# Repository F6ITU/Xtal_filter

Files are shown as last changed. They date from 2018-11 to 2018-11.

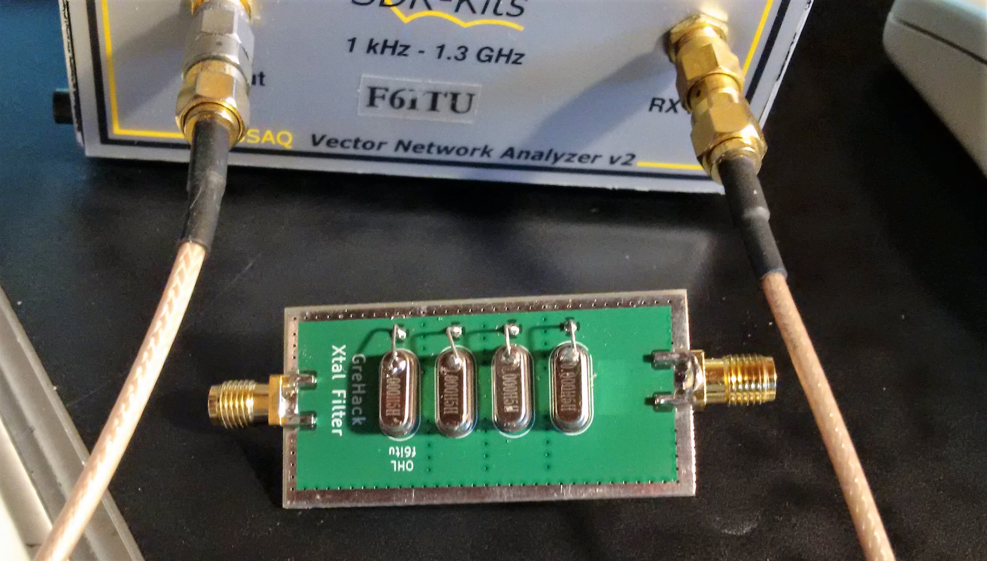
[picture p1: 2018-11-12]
Simu/filtre.jpg

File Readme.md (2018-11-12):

A simple 4th order 10 MHz xtal filter for Grehack 2018 Workshop

A Kicad project for GreHack 2018 workshop

This repository contains a easy to build-easy to reproduce 4th order filter using low cost 10 MHz crystal device in HC49 form factor.

This filter has been designed for educational purpose, and could be the perfect companion for a 10 MHz harmonic-free reference clock 
(gps-do, ocxo or any kind of digitaly generated square wave RF source)

This filter could be used in conjunction with the OCXO based "Aion" reference clock 

https://github.com/F6ITU/OCXO

This board has been designed with Kicad, an Open Source EDA software developped by the CERN.

For better performances, noise imunity and port isolation, this board should be shielded. 

The "Simu" subdirectory contains several simulation and measurement files : 
* 10M-4-5kHz 337ohms 47pf.sch is the "ADDE Filter design" simulation file and schematics of the filter itself
* BOM.doc is the Bill of Material used during the Grehack 2018 workshop
* filtre 10 MHz 4 eme ordre2.png is a screen capture of the filter's response measured with a Network Analyzer (Smith chart and amplitude/insertion losses) 
* filtre 10 MHz 4eme ordre.s2p is the real characteristic of the filter (2 port Touchstone file format). This file could be 
imported in any kind or analyzer or RF simulation software (QUCS, Elsie, VNWA.exe etc)
* filtre.jpg is a picture of the filter itself, without shield

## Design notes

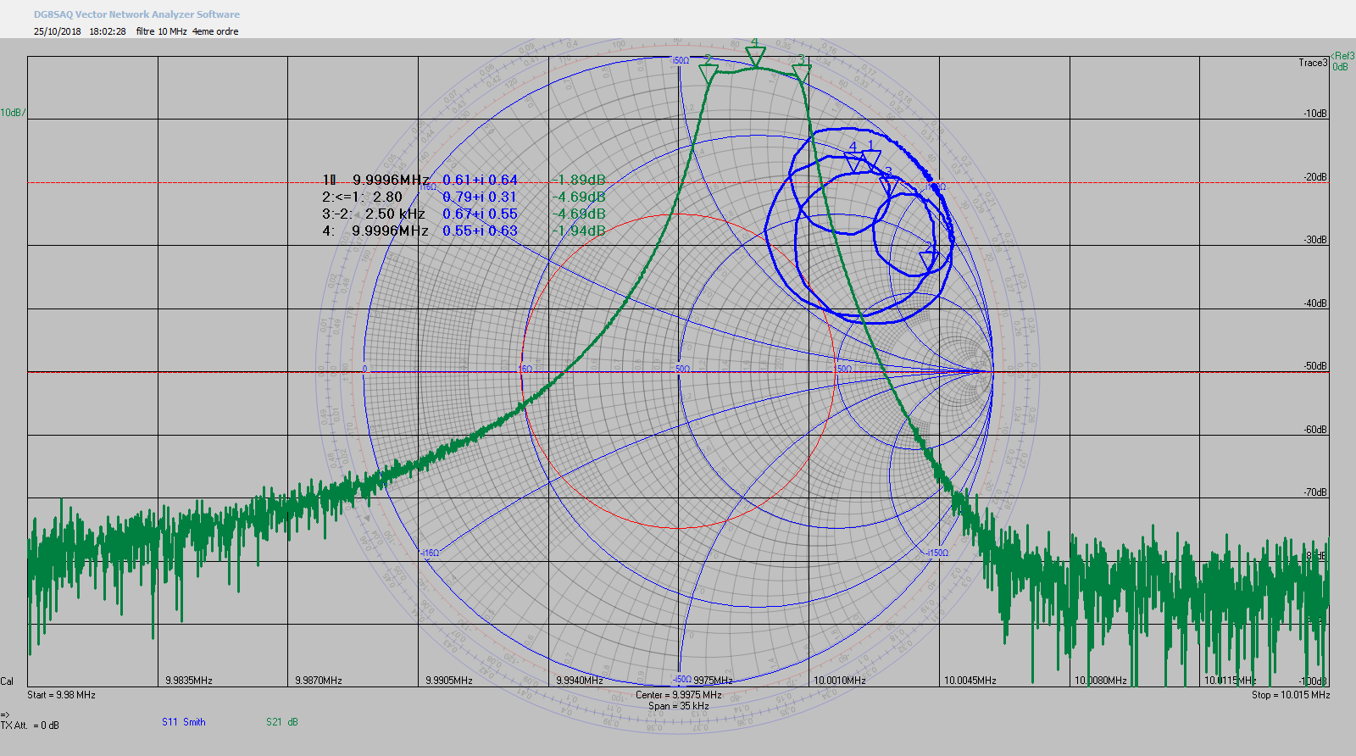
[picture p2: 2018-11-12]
Simu/filtre 10 MHz 4 eme ordre2.png

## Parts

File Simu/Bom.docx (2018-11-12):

Composant | Valeur | Format | Qtté | Couleur | Module
Condensateur | 10 pf | 1206 | 2 | Noir | Filtre Xtal
Condensateur | 120 pf | 1206 | 2 | Double rouge | Filtre Xtal
Condensateur | 47 pf | 0805 | 5 | Non | Filtre Xtal
Crystal | 9.9999MHz | HC49 | 4 | Non | Filtre Xtal
Inductance | 2.2µH | 1206 | 2 | Non | Filtre Xtal
Pcb | | | 1 | Non | Filtre Xtal
SMA connecteur | | Edge | 2 | Non | Filtre Xtal
Pcb | | | 3 | Non | Atténuateur
SMA connecteur | | | 2 | | Atténuateur
Résistances
3dB | 18 Ω série | 0805 | 1 (2) | Rouge | Att 3 dB
3dB | 300 Ω Shunt. | 0805 | 2 (4) | Vert | Att 3 dB
10dB | 68 Ω série | 0805 | 1 (2) | Bleu | Att 10 dB
10dB | 100 Ω Shunt. | 0805 | 2(4) | Noir | Att 10 dB
20 dB | 240 Ω série | 0805 | 1(2) | Rouge-Noir | Att 20 dB
20 dB | 62 Ω Shunt. | 0805 | 2 (4) | Vert-Bleu | Att 20 dB

Composant | Valeur | Format | Qtté | Couleur | Module
Condensateur | 10 pf | 1206 | 2 | Noir | Filtre Xtal
Condensateur | 120 pf | 1206 | 2 | Double rouge | Filtre Xtal
Condensateur | 47 pf | 0805 | 5 | Non | Filtre Xtal
Crystal | 9.9999MHz | HC49 | 4 | Non | Filtre Xtal
Inductance | 2.2µH | 1206 | 2 | Non | Filtre Xtal
Pcb | | | 1 | Non | Filtre Xtal
SMA connecteur | | Edge | 2 | Non | Filtre Xtal
Pcb | | | 3 | Non | Atténuateur
SMA connecteur | | | 2 | | Atténuateur
Résistances
3dB | 18 Ω série | 0805 | 1 (2) | Rouge | Att 3 dB
3dB | 300 Ω Shunt. | 0805 | 2 (4) | Vert | Att 3 dB
10dB | 68 Ω série | 0805 | 1 (2) | Bleu | Att 10 dB
10dB | 100 Ω Shunt. | 0805 | 2(4) | Noir | Att 10 dB
20 dB | 240 Ω série | 0805 | 1(2) | Rouge-Noir | Att 20 dB
20 dB | 62 Ω Shunt. | 0805 | 2 (4) | Vert-Bleu | Att 20 dB

ty

Composant | Valeur | Format | Qtté | Couleur | Module
Condensateur | 10 pf | 1206 | 2 | Noir | Filtre Xtal
Condensateur | 120 pf | 1206 | 2 | Double rouge | Filtre Xtal
Condensateur | 47 pf | 0805 | 5 | Non | Filtre Xtal
Crystal | 9.9999MHz | HC49 | 4 | Non | Filtre Xtal
Inductance | 2.2µH | 1206 | 2 | Non | Filtre Xtal
Pcb | | | 1 | Non | Filtre Xtal
SMA connecteur | | Edge | 2 | Non | Filtre Xtal
Pcb | | | 3 | Non | Atténuateur
SMA connecteur | | | 2 | | Atténuateur
Résistances
3dB | 18 Ω série | 0805 | 1 (2) | Rouge | Att 3 dB
3dB | 300 Ω Shunt. | 0805 | 2 (4) | Vert | Att 3 dB
10dB | 68 Ω série | 0805 | 1 (2) | Bleu | Att 10 dB
10dB | 100 Ω Shunt. | 0805 | 2(4) | Noir | Att 10 dB
20 dB | 240 Ω série | 0805 | 1(2) | Rouge-Noir | Att 20 dB
20 dB | 62 Ω Shunt. | 0805 | 2 (4) | Vert-Bleu | Att 20 dB

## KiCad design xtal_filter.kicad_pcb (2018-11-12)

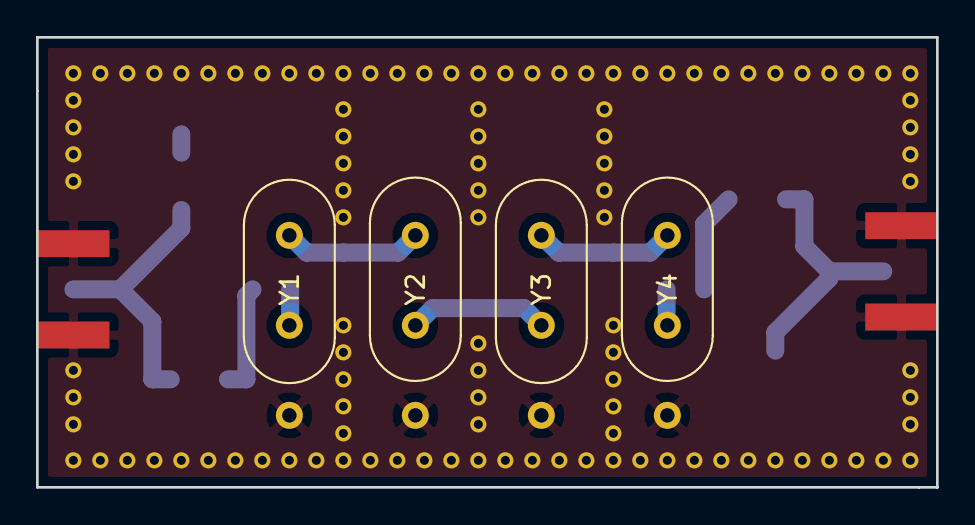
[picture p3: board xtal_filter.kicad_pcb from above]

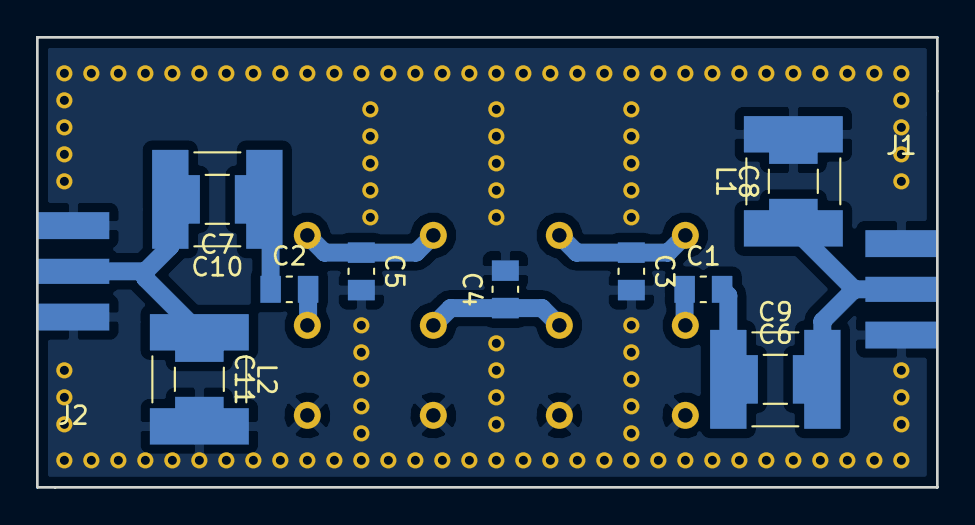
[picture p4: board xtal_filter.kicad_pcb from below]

Board: 2 copper layers, 50.0 x 25.0 mm, 19 parts (15 on the bottom side), 10 nets.

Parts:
C1, C2, C3, C4, C5: C_Small; C_0805_2012Metric_Pad1.15x1.50mm_HandSolder
C6, C7, C8, C11: C_Small; C_1210_3225Metric_Pad1.24x2.70mm_HandSolder
C9, C10: C_Small; C_2220_5650Metric_Pad2.02x5.50mm_HandSolder
J1, J2: Conn_Coaxial; SMA_EDGE_NRW
L1, L2: L_Small; C_2220_5650Metric_Pad2.02x5.50mm_HandSolder
Y1, Y2, Y3, Y4: 10M; Crystal_HC49-U-3Pin_Vertical

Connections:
GND: C3.2, C4.2, C5.2, C8.2, C11.2, J1.2, J2.2, L1.2, L2.2, Y1.3, Y2.3, Y3.3, Y4.3
unnamed: C1.1, Y1.1
unnamed: C1.2, C6.1, C9.1
unnamed: C2.2, Y4.2
unnamed: C3.1, Y1.2, Y2.1
unnamed: C4.1, Y2.2, Y3.1
unnamed: C5.1, Y3.2, Y4.1
unnamed: C6.2, C8.1, C9.2, J1.1, L1.1
unnamed: C2.1, C7.1, C10.1
unnamed: C7.2, C10.2, C11.1, J2.1, L2.1
